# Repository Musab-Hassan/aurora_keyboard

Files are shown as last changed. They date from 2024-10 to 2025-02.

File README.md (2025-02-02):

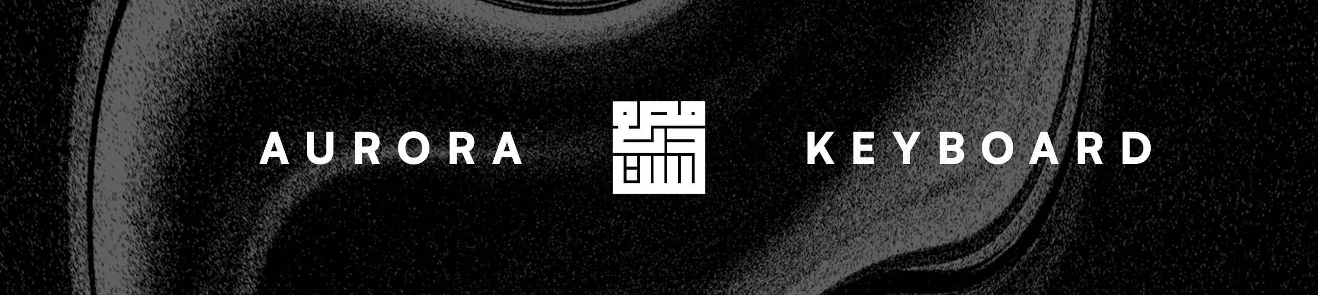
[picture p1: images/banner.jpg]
Aurora Keyboard ⌨️
# 

The Aurora keyboard is a beautifully designed fully split, wireless, ergonomic keyboard that you can build yourself.

**The full build guide can be found in `build_guide/`.**

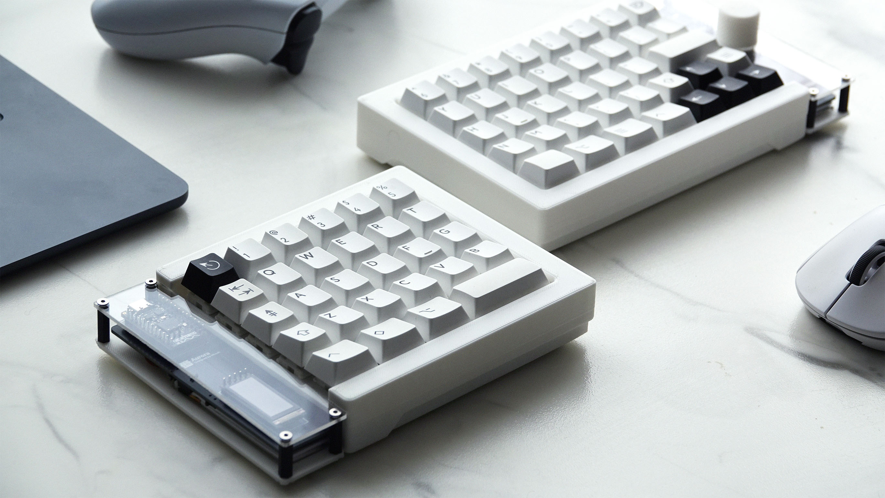
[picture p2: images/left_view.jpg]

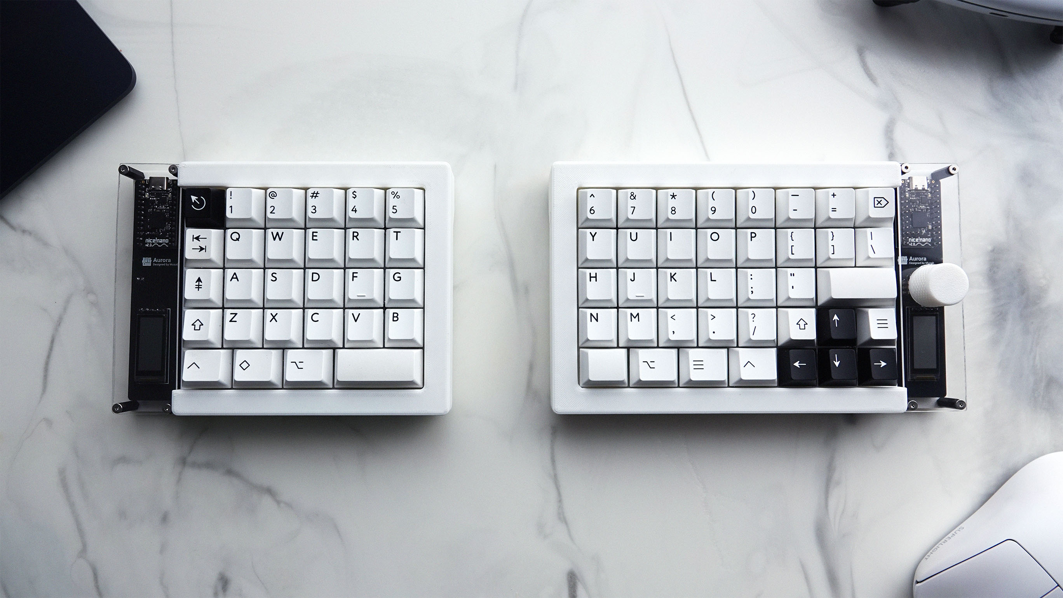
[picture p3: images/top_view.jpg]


**Key Features:**

- Bluetooth and dongle switching
- Ortholinear layout
- 65% layout (full layout with no compromises)
- Per-key RGB (if you can solder them)
- Support for any MX switches and keycaps
- OLED Screen (nice!view)
- Volume knob
- Hotswappable
- ZMK Firmware

## Repo Contents

- **STL Case Files:** 3D-printing-ready case files. You can print these without any CAD skills.
- **SLDPART Case Files:** SolidWorks case files. Modify these to create a custom layout. (Sorry, SolidWorks is the only CAD software I'm proficient in.)
- **Completed PCB Files:** Fabrication-ready routed PCB files, modifiable in KiCAD or Altium. Export them to `.gerber` files for fabrication.
- **Ergogen Files:** Ergogen configuration files used to generate the unrouted PCB. There are two separate folders since the keyboard is asymmetrical. Modify only if fundamental PCB changes are needed.

### Not Included in This Repo

- **ZMK Config:** The ZMK Firmware configuration is stored in [a separate repository](https://github.com/Musab-Hassan/zmk-config-aurora) and is not included here.

## Case Design

The Aurora keyboard uses a [plate-mounted style](https://www.keyboard.university/200-courses/keyboard-mounting-styles-4lpp7) with a top plate and a flat bottom base for each half. The PCB, microcontroller, and nice!view screens are exposed at the open ends and are covered by an acrylic piece.

Due to its ergonomic design and full 65% layout, the cases are asymmetrical, with the right side being larger than the left.

All files were designed in SolidWorks, but they can be opened and modified in other CAD/CAM software.

### Dongle and Bluetooth Switching

The case files also include a dongle case. This dongle is a third nice!nano that functions as a keyboard dongle when connected to a computer via a USB cable or USB-C male-to-male adapter. The dongle case also includes a dongle cover, which, when glued together, allows the dongle to slot into the left side of the keyboard.

The left side features a slot for the dongle. If 3-pin magnetic pogo connector is added to the pogo connector holes within both the dongle case and the left side keyboard slot, the dongle can then magnetically attach and automatically switch to Bluetooth by using the left-side battery when it slots in.

Refer to the build guide for more details.

## PCB Design

The PCB layout and unrouted PCB were generated using Ergogen. Since the two halves have different layouts, separate folders exist for each. My Ergogen skills were not sufficient to configure both in one file.

After Ergogen, the PCB was routed in KiCAD. Routed PCB files are in the `pcb` directory and are fabrication-ready. Download the zip files from the `pcb/gerber` directory and then order them for fabrication.

You can order the PCBs from manufacturers such as PCBWay or JLCPCB.

## Parts List

This list includes all external parts required, excluding the PCB and 3D-printed case files. I’ve also provided the sources where I purchased these parts. However, they may not be the cheapest or best sources. Switches and keycaps are personal preference and should be a significant part of your budget.

### Required Parts

| Part | Quantity | Where I got them from |
| --- | --- | --- |
| nice!nano | 3 (2 if no dongle) | [Typeractive](https://typeractive.xyz/products/nice-nano) |
| nice!view | 2 | [Typeractive](https://typeractive.xyz/products/nice-view) |
| 1N4148W SMD diodes | 70 | [Typeractive](https://typeractive.xyz/products/smd-diodes) |
| MX Hotswap sockets | 70 | [Amazon](https://www.amazon.ca/dp/B0972HB9GY) |
| 750 mAh Thin LiPo Battery | 2 | [Typeractive](https://typeractive.xyz/products/lithium-battery-750mah) |
| JST PH 2.0mm Battery Jack | 2 | [Typeractive](https://typeractive.xyz/products/battery-jack) |
| EC11 Encoder | 1 | [Digikey](https://www.digikey.ca/en/products/detail/alps-alpine/EC11E15244B2/19529170) |
| 0.08" Acrylic Sheet (8" x 12") | 1 | [Amazon](https://www.amazon.ca/dp/B0BK3DN8JR) |
| Alps Micro Switch | 2 | [TyperActive](https://typeractive.xyz/products/power-switch) |
| Panasonic EVQPU Reset Button | 2 | [Typeractive](https://typeractive.xyz/products/reset-button) |
| PCB Mount Stabilizers | 4 | [KBDFans](https://kbdfans.com/collections/keyboard-stabilizer/products/cherry-clip-in-stabilizer-pcb-mount) |
| MX Switches (Preference: I chose Gateron Smoothies) | 70 | [KBDFans](https://kbdfans.com/products/gateron-smoothie-linear-switch) |
| MX Keycaps (Preference: I chose PBTFans BOW) | 70 | [KBDFans](https://kbdfans.com/products/pbtfans-doubleshot-bow) |
| M2.5 6mm Countersunk Screw | 12+ | [Amazon](https://www.amazon.ca/dp/B075RCP71G) or [McMaster Carr](https://www.mcmaster.com/92010A016) |
| M2.5 8mm Hex Standoff | 8+ | [Amazon](https://www.amazon.ca/dp/B0788FR59P) or [McMaster Carr](https://www.mcmaster.com/95947A003) |
| M2.5 14mm Hex Standoff | 8+ | [Amazon](https://www.amazon.ca/dp/B0788FR59P) or [McMaster Carr](https://www.mcmaster.com/95947A009) |

### Optional But Recommended Parts

| Part | Quantity | Why | Where I got them from |
| --- | --- | --- | --- |
| 3 Pin Magnetic Pogo Connector  | 2 | Allows dongle to magnetically snap in and switch to bluetooth | [Amazon](https://www.amazon.ca/dp/B0CPJHQK2F) |
| Rubber Feet  | 8 | Prevents keyboard from slipping | [Amazon](https://www.amazon.ca/dp/B07CNQC695) |
| Neodymium Bar Magnets (60mm x 10mm x 3mm) | 2 | Allows the keyboard to magnetically snap when connected together (case plate has a slot for magnets) | [Amazon](https://www.amazon.ca/dp/B09TKMRRRC) |
| Keyboard Lube or Di-electric grease | 1 | If you want your keyboard to sound good you can lube the switches for it to sound even better (not recommended unless you are very ambitious about keyboards) | [Amazon](https://www.amazon.ca/dp/B09B9RL1QQ) |
| Neoprene Foam Sheet | 1 | Allows you to dampen keyboard sound so it sounds better. Again not recommended unless you really like dampened keyboard sounds. | [Amazon](https://www.amazon.ca/dp/B0B88BLNGQ) |
| SK6812Mini RGB LED | 70 | RGB per key backlight. Only get these if you are very experienced with SMD soldering. They are very difficult to solder by hand. There is also no support in the Aurora ZMK configuration for RGB yet as I am unable to solder them. If you do solder them you will need to add the backlight option in the ZMK config yourself for them to work. | [ClicketySplit](https://clicketysplit.ca/products/sk6812mini-programmable-rgb-led) |

### Required Tools

- Soldering iron (preferably with temperature control)
- Solder (preferably nothing larger than 0.8mm)
- Flux (optional but recommended)
- Tweezers
- FDM or Resin 3D Printer or at least access to one
- Screw driver with the appropriate bit depending on your screws

## License

GPL V3 License

Have fun with your build!

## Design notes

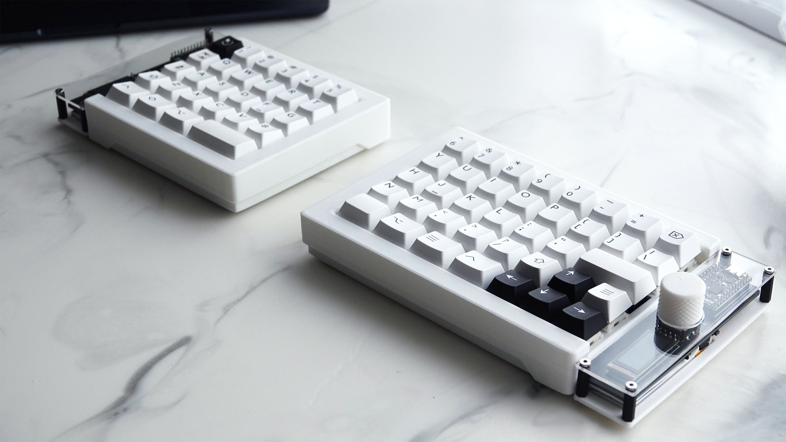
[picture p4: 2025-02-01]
images/right_view.jpg

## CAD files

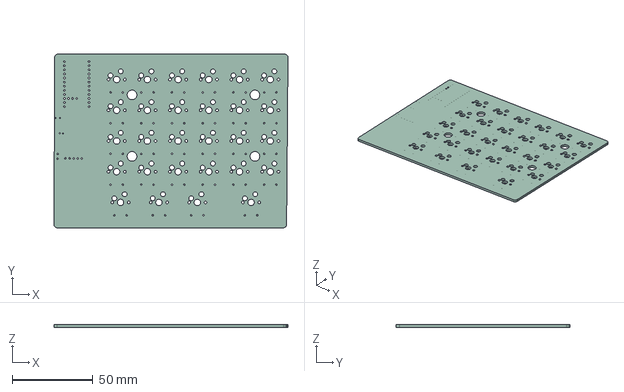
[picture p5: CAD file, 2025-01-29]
case/CAD/pcb/left-pcb.step
145.1 x 107.7 x 1.60 mm

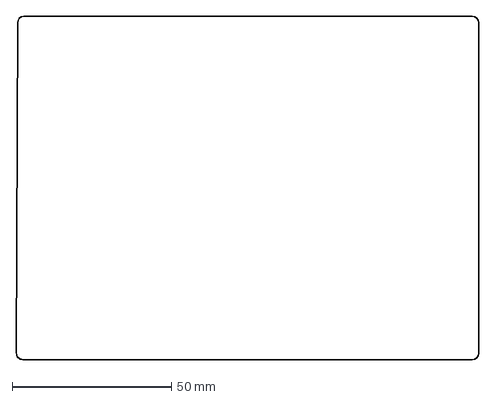
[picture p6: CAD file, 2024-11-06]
left_ergogen/output/outlines/board.dxf
145.1 x 107.7 mm

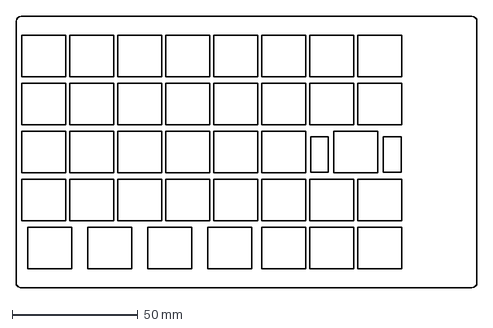
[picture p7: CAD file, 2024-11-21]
right_ergogen/output/outlines/combo.dxf
182.9 x 107.7 mm

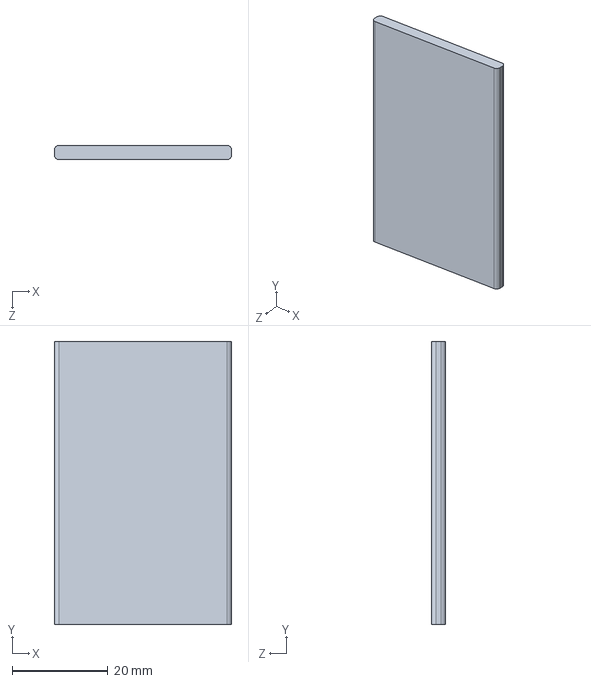
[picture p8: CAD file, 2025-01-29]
case/CAD/battery_placeholder.SLDPRT
37.0 x 59.0 x 3.00 mm

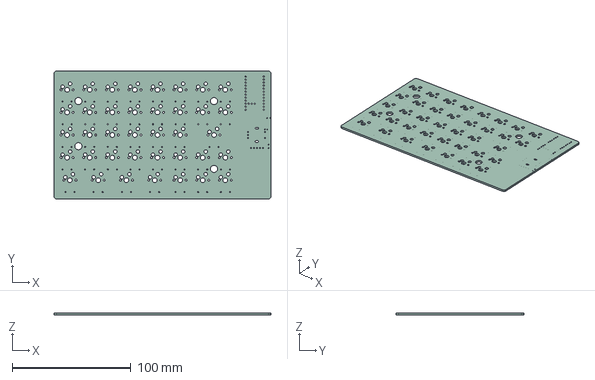
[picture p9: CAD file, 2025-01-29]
case/CAD/pcb/right-pcb.step
182.9 x 107.7 x 1.60 mm

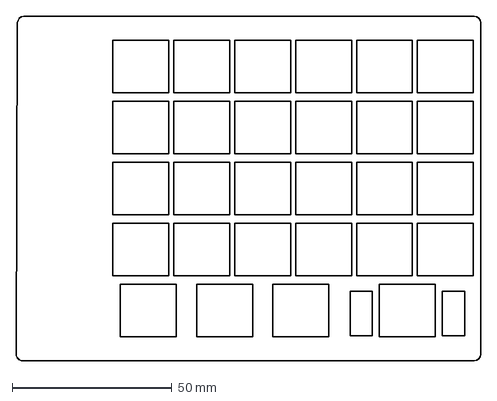
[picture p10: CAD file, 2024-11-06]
left_ergogen/output/outlines/combo.dxf
145.1 x 107.7 mm

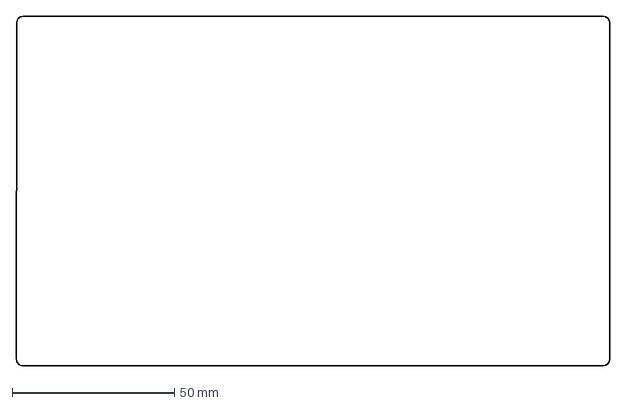
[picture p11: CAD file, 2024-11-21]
right_ergogen/output/outlines/board.dxf
182.9 x 107.7 mm

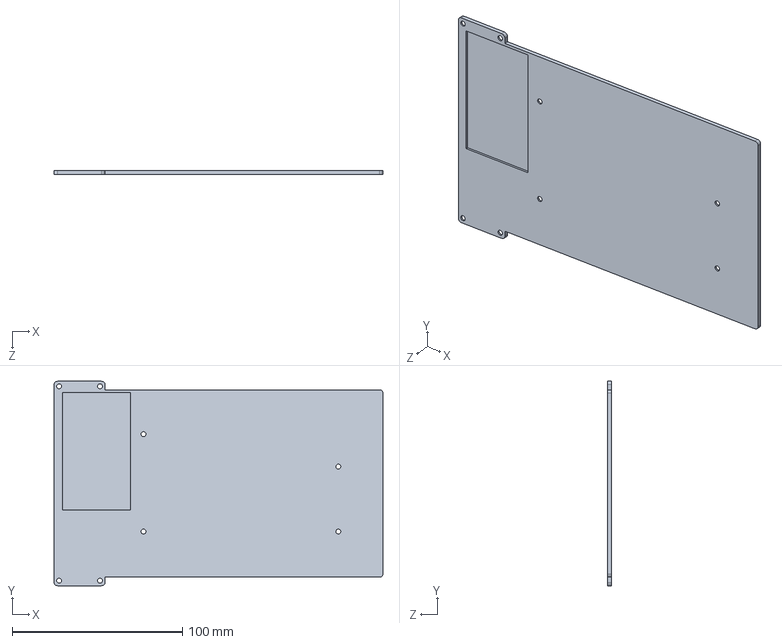
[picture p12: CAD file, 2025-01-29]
case/CAD/right_base.SLDPRT
193.0 x 120.0 x 2.20 mm

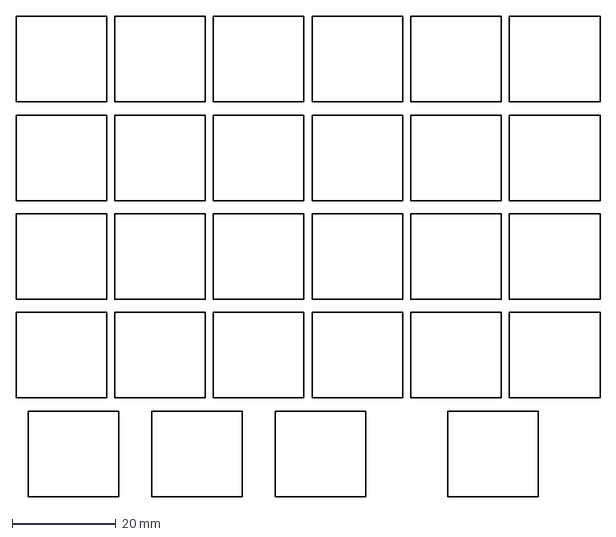
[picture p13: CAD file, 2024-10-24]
left_ergogen/output/outlines/keys.dxf
112.8 x 92.7 mm

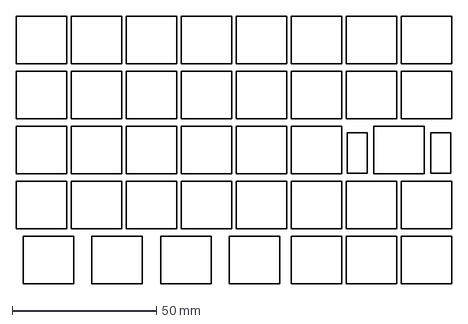
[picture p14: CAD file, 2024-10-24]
right_ergogen/output/outlines/keys_w_stabs.dxf
150.8 x 92.7 mm

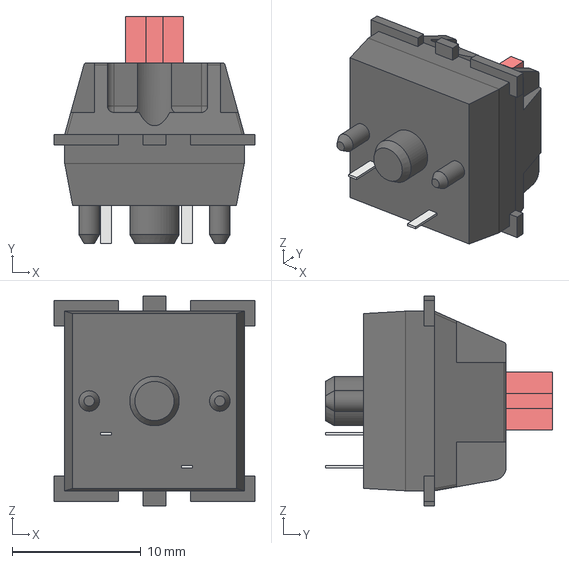
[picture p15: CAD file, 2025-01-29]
case/CAD/switch.step
15.6 x 17.7 x 16.3 mm

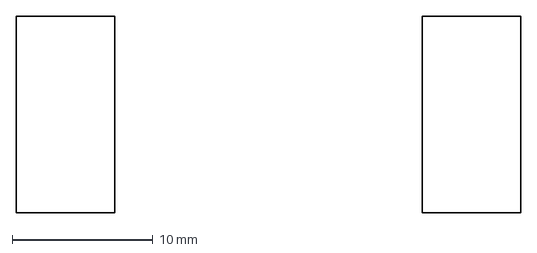
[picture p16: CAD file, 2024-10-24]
left_ergogen/output/outlines/2u_stabilizer.dxf
35.8 x 14.0 mm

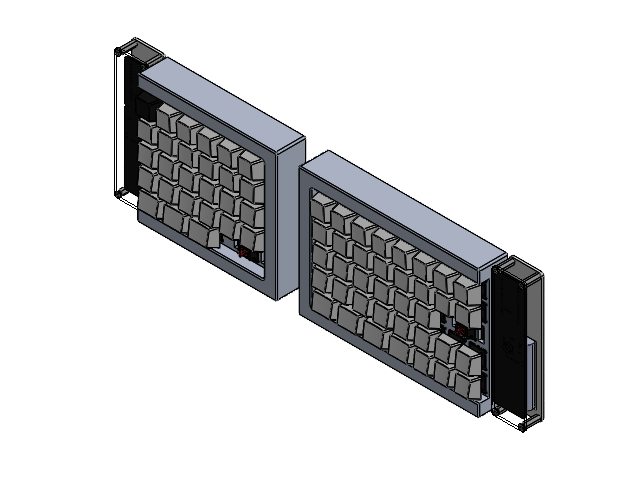
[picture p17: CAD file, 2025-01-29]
case/CAD/combined_assembly.SLDASM
right_plate
right-pcb
switch x 38
1x1 R1 v23 x 17
1x1 R2 v8 x 12
1x1 R3 v8 x 14
1x1 R4 v6 x 14
1x1.25 R1 v7 x 7
92010A018_Passivated 18-8 Stainless Steel Phillips Flat Head Screw x 32
95947A007_Aluminum Female Threaded Hex Standoff x 8
95947A009_Aluminum Female Threaded Hex Standoff x 8
battery_placeholder x 2
right_base
acrylic_holed_shield
left_plate
left_base
Component1.step x 28
Component2.step x 28
acrylic_shield
left-pcb

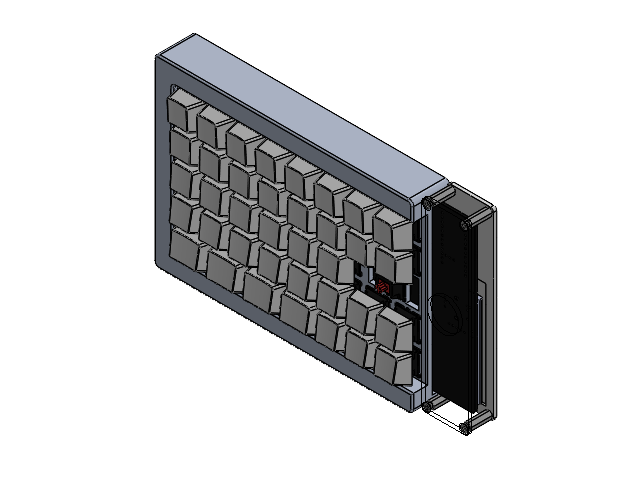
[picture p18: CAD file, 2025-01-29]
case/CAD/right_assembly.SLDASM
right_plate
right-pcb
switch x 38
1x1 R1 v23 x 11
1x1 R2 v8 x 6
1x1 R3 v8 x 8
1x1 R4 v6 x 8
1x1.25 R1 v7 x 4
92010A018_Passivated 18-8 Stainless Steel Phillips Flat Head Screw x 16
95947A003_Aluminum Female Threaded Hex Standoff x 4
95947A009_Aluminum Female Threaded Hex Standoff x 4
battery_placeholder
right_base
acrylic_holed_shield

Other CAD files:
case/CAD/keycaps/1x1 R2 v8.SLDPRT
case/CAD/keycaps/1x1 R3 v8.SLDPRT
case/CAD/keycaps/1x1.25 R1 v7.SLDPRT
case/CAD/keycaps/1x1.25 R4 v6.SLDPRT
case/CAD/acrylic_holed_shield.SLDPRT
case/CAD/acrylic_shield.SLDPRT
case/CAD/dongle.SLDPRT
case/CAD/dongle_cover.SLDPRT
case/CAD/keycaps/1x1 R1 v23.SLDPRT
case/CAD/keycaps/1x1 R4 v6.SLDPRT
case/CAD/keycaps/1x1.25 R2 v4.SLDPRT
case/CAD/keycaps/1x1.25 R3 v5.SLDPRT
case/CAD/left_base.SLDPRT
case/CAD/left_plate.SLDPRT
case/CAD/pcb/left-pcb.SLDPRT
case/CAD/pcb/right-pcb.SLDPRT
case/CAD/right_plate.SLDPRT
case/CAD/standoff_hardware/92010A018_Passivated 18-8 Stainless Steel Phillips Flat Head Screw.SLDPRT
case/CAD/standoff_hardware/95947A003_Aluminum Female Threaded Hex Standoff.SLDPRT
case/CAD/standoff_hardware/95947A009_Aluminum Female Threaded Hex Standoff.SLDPRT
case/CAD/switch.SLDPRT
case/STL/acrylic_holed_shield.STL
case/STL/acrylic_shield.STL
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

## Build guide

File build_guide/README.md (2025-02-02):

# Aurora Keyboard Build Guide

Before getting started, ensure you have fully read through the README.md file in the project root. Make sure you have all the required parts and tools before getting started.

This guide will cover how I built the keyboard and will provide the main steps however it expects you to already understand how mechanical keyboard work and have experience with soldering small components. Having some experience with a soldering iron is sufficient if you decide to just go with the required soldering. The only part that requires exceptional hand soldering skills or a reflow station is if you choose to solder the SMD LEDs. They are exceptionally difficult to solder by hand however they are neither required nor recommended and are entirely optional.

This guide also expects that you made no changes to the pin layout on the nice!nano on each side and are going to use a 3rd nice!nano as a dongle. If you chose to not do these, you can still follow the guide but must [modify the ZMK config](https://github.com/Musab-Hassan/zmk-config-aurora/tree/main/config/boards/shields/aurora) for your keyboard to function properly.

## PCB Ordering

Before starting the build also ensure you have both PCBs and there are no major defects on them. You can order both PCBs from JLCPCB or PCBWay (I chose JLC).

1. Go to the [JLCPcb website](https://jlcpcb.com/)
2. Drag and drop one of the gerber zip files from `pcb/gerber`
3. You only have to change the color (I chose black) and just leave everything else at default
4. Add it to cart and repeat the same steps for the other zip file
5. Place your order

Once you have your PCB we are ready to build!

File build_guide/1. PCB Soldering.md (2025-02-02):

# Soldering the PCB

This part of the guide will walk you through the process of soldering all the necessary components onto the PCB. Follow each step carefully to ensure the keyboard functions properly. If you have a voltmeter, you can perform continuity checks to ensure that all your joints are solid.

## Required Tools and Materials

For this part, you will require the following tools from the README. Ensure you use the correct soldering temperature for your solder (usually higher than 400°C is good). Cold joints will cause problems.

- Soldering iron (preferably with temperature control)
- Solder (preferably nothing larger than 0.8mm)
- Flux (optional but recommended)
- Tweezers

## Board Orientation

Throughout this soldering guide, there will be references to the board back, front, left, and right. It's important to understand what these mean.

The shorter PCB is the "left PCB," while the longer PCB is the "right PCB." Both of these PCBs have solder points on the front and the back. The front of both PCBs is where the logo and the screen are located (see picture below).

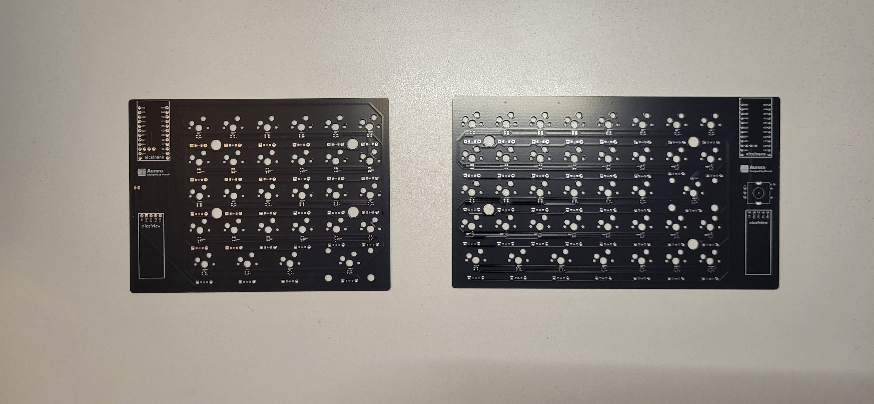
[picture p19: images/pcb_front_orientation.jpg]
Front Orientation


The bottom side is where the diodes and other hidden components go (see picture below).

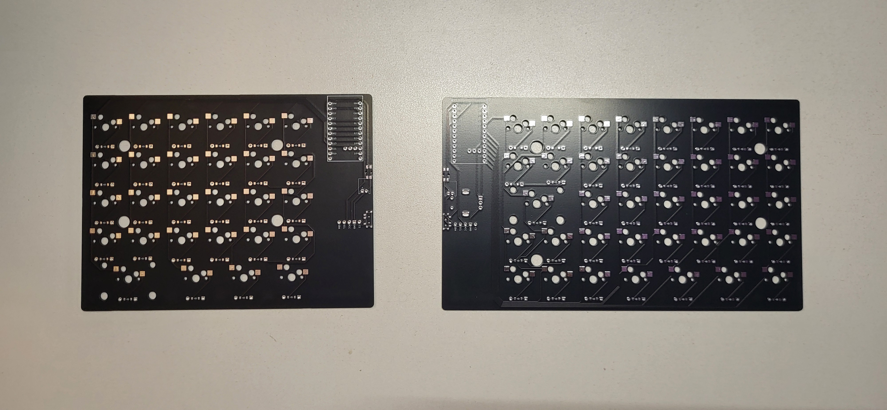
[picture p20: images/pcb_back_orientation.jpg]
Back Orientation


## Step-by-Step Soldering Guide

### Before Starting

If you plan to have per-key RGB backlighting, start by soldering the LEDs. These are surface-mount components and require precision, so doing them first ensures nothing gets messed up once everything else is soldered on. The pads are labeled in the PCB schematic, and you must align them appropriately. For this step, you are on your own as this is the only component I have not added to my build. The ZMK configuration will also need to be modified when you get to Firmware Flashing.

If you do not want to modify the firmware configuration or don't care about RGB, you can skip this step.

### 1. Solder Diodes

Start by soldering the diodes. Each key needs a diode. You can find the diode pads on the back side of the PCB.

Ensure the diode line aligns with the cathode on the solder mask image (see image below).

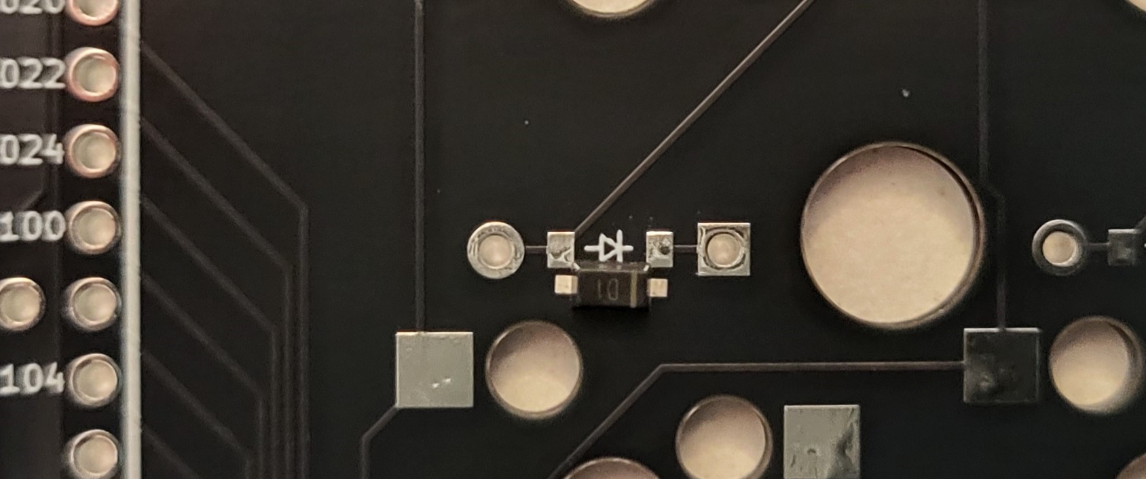
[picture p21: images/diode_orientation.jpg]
Diode Orientation


Make sure you solder them on both PCBs.

> #### Why do we need diodes?
>
> Each key is connected to a column and a row, which identifies it to the microcontroller. This "matrix" allows a lot of keys to exist without using many pins on a microcontroller. Diodes ensure that when a key is pressed, it is always detected even when multiple keys are pressed.

### 2. Solder Hotswap Sockets

The next step is to solder the hotswap sockets to their pads. The hotswap socket pads are located on the same side of the PCB as the diodes. Just like diodes, each key needs a hotswap socket.

Hotswap sockets allow you to easily click in switches and replace them in the future without having to desolder them each time.

The sockets will fit in both orientations, so ensure you orient them in a way that does not block the stem hole for your switches. See the image below for the correct orientation.

|❌ Wrong Orientation|✔️ Correct Orientation|
|--|--|
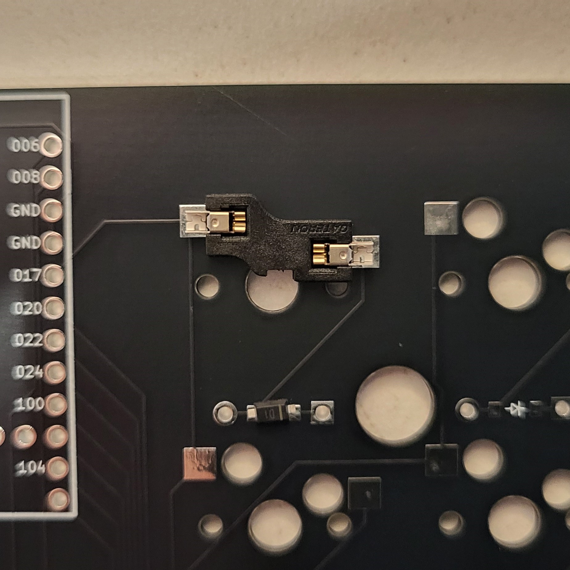
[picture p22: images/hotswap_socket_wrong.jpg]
Incorrect Orientation
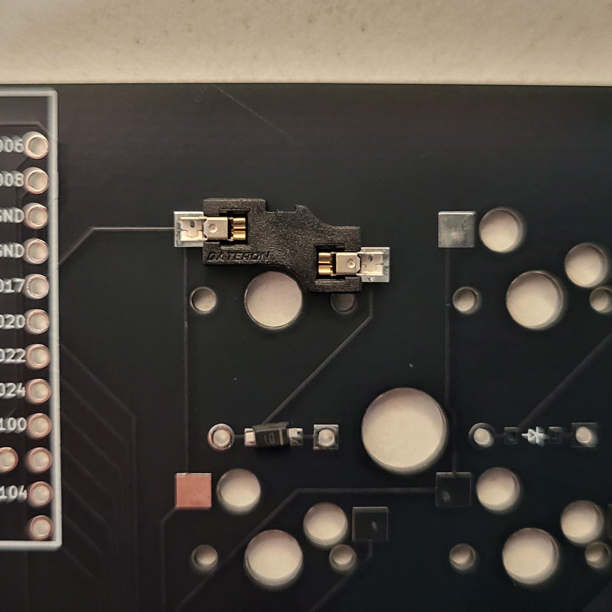
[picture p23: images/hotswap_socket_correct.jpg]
Correct Orientation
|||

Make sure you solder them on both PCBs.

### 3. Solder Power and Reset Switches

Similar to the diodes, continue by soldering the legs on both the power and reset switches. There is only one correct orientation for them, so this step should be easier compared to soldering diodes.

Your final soldered joints should look something like this:

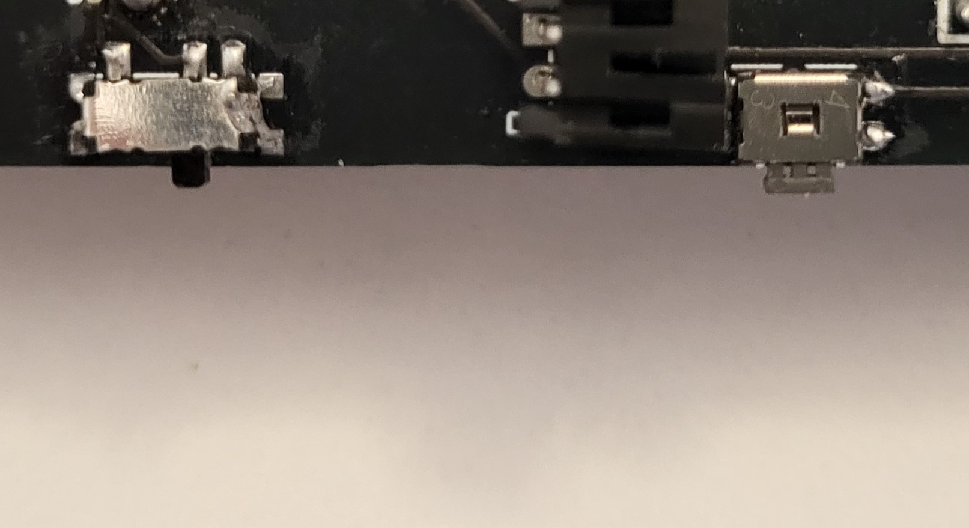
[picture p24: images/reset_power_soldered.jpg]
Soldered joints for power and reset switches


Make sure you solder them on both PCBs.

### 4. Solder Both nice!nanos

The next step is to solder the nice!nano microcontroller onto both boards. The microcontroller should come with three pin headers. Slot them into their respective holes on the front of the PCB and solder the legs sticking out on the back side of the PCB. Ensure the other end of the pins sticks out on the top and not the bottom, as the microcontroller will be soldered onto them.

After soldering the headers, slide the microcontroller onto the pins exposed on the top and solder each pin on the microcontroller. Ensure you make proper joints with a reasonable amount of solder, as cold joints here can cause problems.

Your final solder points should look like this (the mess is because of flux and definitely not because of my soldering skills):

|Front|Back|
|--|--|
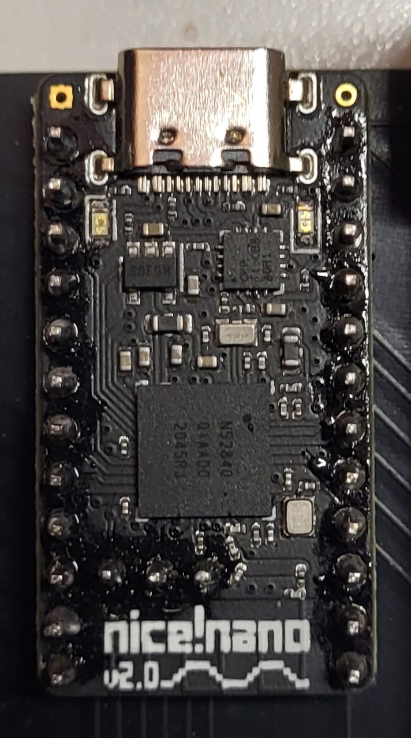
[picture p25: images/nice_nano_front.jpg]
Front
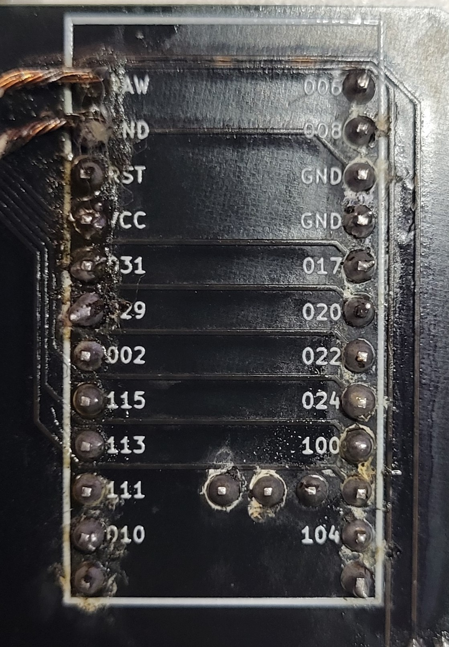
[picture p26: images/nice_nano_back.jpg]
Back
|||

Make sure you solder a nice!nano on both the right and left PCBs.

### 5. Solder Screens

Just like the microcontroller, the nice!view screens should also come with one pin header each. Slot this pin header into its hole and solder the exposed pins on the back of the board.

After soldering the headers, slide the nice!view screens onto the pins exposed on the top and solder each pin. Ensure you make proper joints with a reasonable amount of solder, as cold joints here can cause problems.

Your final solder points should look like this (the mess is because of flux and definitely not because of my soldering skills):

|Front|Back|
|--|--|
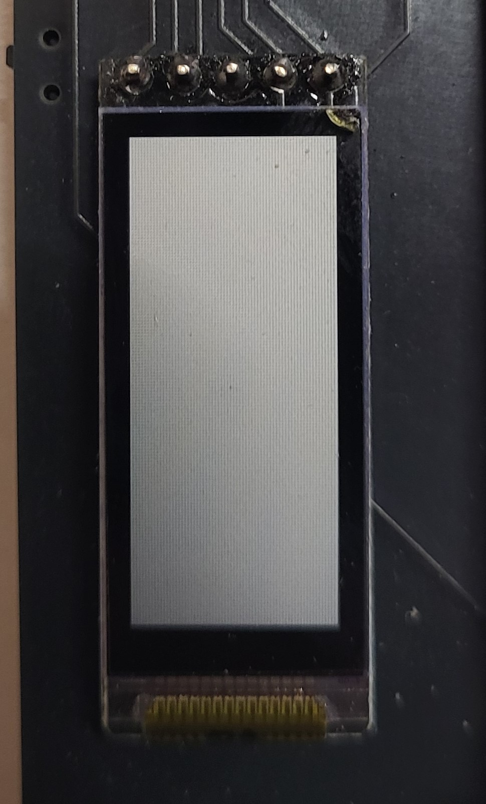
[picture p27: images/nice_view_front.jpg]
Front
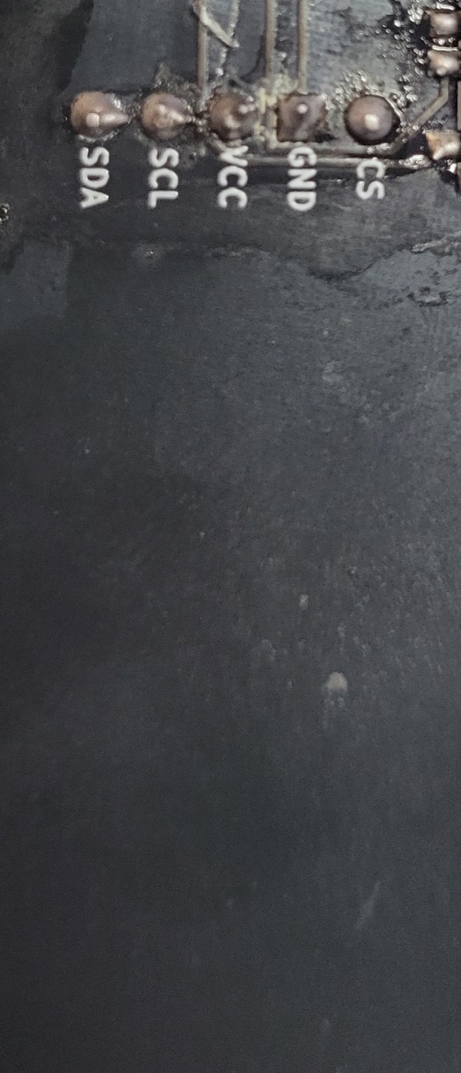
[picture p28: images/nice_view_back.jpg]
Back
|||

### 6. Solder JST Jack

Before starting this step, ensure your battery has a male jack so it can connect to the JST Jack. If it does not (bare wires), you will need to purchase a battery connector and add it to the battery end so it can be connected to the jack. You can also skip this step by just soldering the battery wires directly to the JST Jack holes, however I would not suggest this as this will make future repairs annoying.

If you do have a connector, you can start soldering the JST battery jack now.

Align the JST battery jack on the back side of the PCB. Ensure it is oriented according to the direction marked on the PCB. The exposed pins should stick out on the front of the PCB, where you will solder them. If you solder the jack in the wrong orientation, the battery will not be able to power the microcontroller.

Do not plug in the battery yet; we will do this later during the case assembly.

The final soldered jack should look like this:

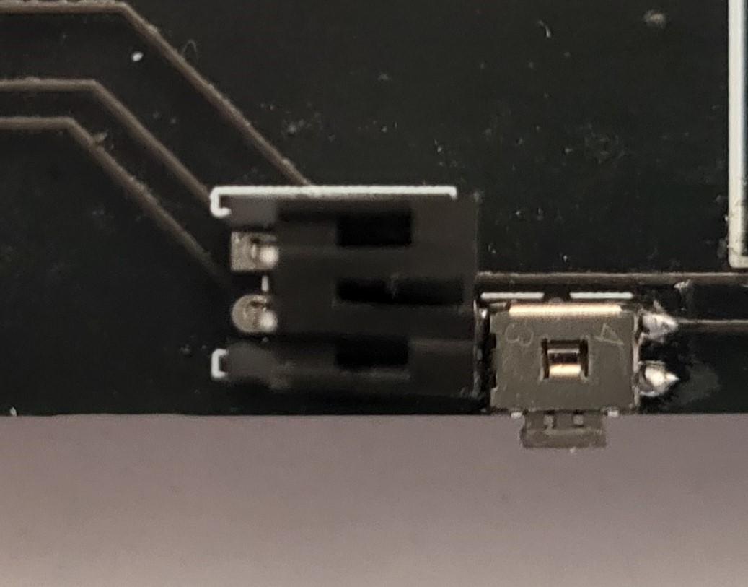
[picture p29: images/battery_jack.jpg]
Battery Jack


Once soldered to both sides, the left PCB is complete. The right PCB just needs one last component to be soldered.

### 7. Solder Right Encoder

Finally, solder the rotary encoder to the right PCB. The encoder should face the front with its legs and pins pushed through their holes.

Once inserted, solder the exposed pins on the back. Leave the legs as they are, as they provide stability but do not have any electrical connections.

### 8. Mount your stabilizers

We are now done with soldering however we do need to add one last component which is mounting our stabilizers to the PCB. The wider keys such as the space bar on the left and the enter on the right side need them to not wobble when they are pressed.

You can find tutorials online on how to mount stabilizers to a PCB (I suggest [this tutorial](https://www.youtube.com/watch?v=kWlRucYPb5g)). I would also highly suggest [lubing and then adding some dampening material](https://www.youtube.com/watch?v=-vhpHjlkRgQ) under your stabilizers to reduce rattling when you press the larger keys.

## Final Checks

As part of the final checks:

- Inspect all solder joints for cold solder or bridges.
- Ensure all components are securely attached.

Congratulations! You’ve successfully soldered the PCB for your Aurora Keyboard.

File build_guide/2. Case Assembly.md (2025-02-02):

# Case Assembly

Assembling the case is the final step in building your keyboard's hardware. This is where you will secure all the components together and have a ready to use keyboard. Follow each step carefully to ensure your build turns out beautiful.

## Required Tools and Materials

For this part, you will only need a screwdriver with a bit appropriate for the screws you purchased.

Also, ensure you have all the printed case STLs with all support material removed.

The printed files required for this part are:

- Left Plate (provided as STL)
- Right Plate (provided as STL)
- Left Base (provided as STL)
- Right Base (provided as STL)
- Right Encoder Knob ([Get from Printables](https://www.printables.com/model/347536-encoder-knob))

> I printed all my parts with a Bambu labs P1P (0.4mm nozzle) printer in white PLA. I would suggest using a slow speed and enabling supports. You can also enable ironing on the top surface for an even better finish.

You can also resin print the "acrylic_cover" files; however, I would advise getting them laser-cut in acrylic or hand-cutting them from an acrylic sheet using a drill and snapping them. See the acrylic piece step below for more details on how to do this.

## Step-by-Step Case Assembly Guide

### 1. Click in Switches

The PCB is a floating PCB, meaning it has no support from underneath or above and is held to the case exclusively by the switches clicked in from the top plate. This simplifies assembly and prevents 3D printing imperfections from interfering with PCB spacing.

To begin assembly, align the PCB with the top plate. Align the hotswap sockets with the cutouts for each key in the plate and start pushing in switches from the top. Do this evenly by starting from each corner and then working toward the middle. Once they are all aligned, give them a firm push to ensure they are properly seated within the hotswap sockets on the PCB. As you insert more switches, the PCB will become more securely attached to the top plate.

Your final PCB and plate assembly should look like the following image.

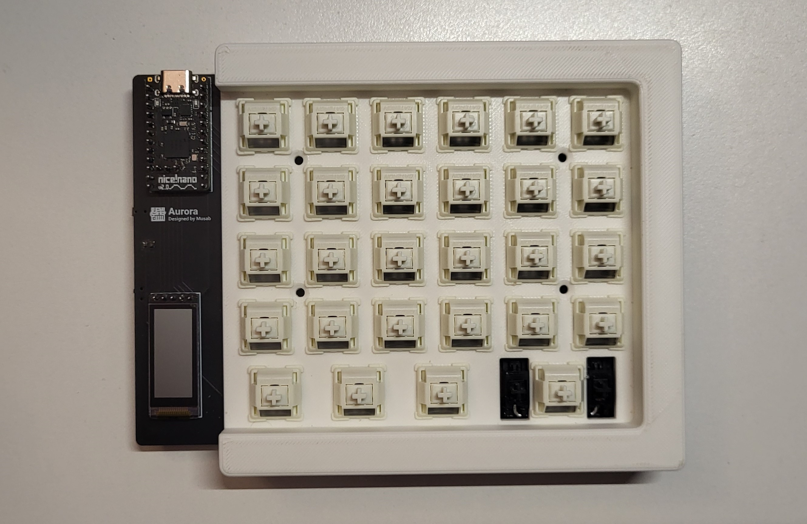
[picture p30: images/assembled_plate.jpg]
Assembled Plate


Ensure this is done for both halves.

**Optional Feature:** There is a slot under the plate to add a neodymium magnet so your keyboard can magnetically attach to the other half when it gets close. You can slot your magnet here (ensure it's in its correct orientation so it attracts) and just hot glue it so it stays secure.

### 2. Prepare Base

Now, prepare the base for mounting with the top plate.

Start by screwing four M2.5 8mm Hex Standoffs with screws from the bottom of the base where the plate holes and base holes align.

Next, screw four M2.5 14mm Hex Standoffs into the end holes where the acrylic piece will be screwed on top.

Lastly, apply [thin double-sided tape](https://www.amazon.ca/dp/B00BXYWXY8) to the cavity in the base where the battery will sit. Align the battery to the bottom and left of the cavity and tape it down with the double-sided tape.

As an additional layer of protection, tape a small piece of thin foam (often included with switches) on top of the battery. This prevents accidental punctures from exposed pins and keeps the battery safe from pressure or sharp contacts.

Ensure you repeat this for both sides and both batteries.

Your prepared base should look like the following image:

**Optional Features:** As an extra noise damper, you can add a layer of Neoprene foam (listed in optional parts) to the base to help with noise reduction and change your keyboard's sound profile. You can also add rubber feet to the bottom to reduce slipping. I have included both in my build, which you can see in the image below.

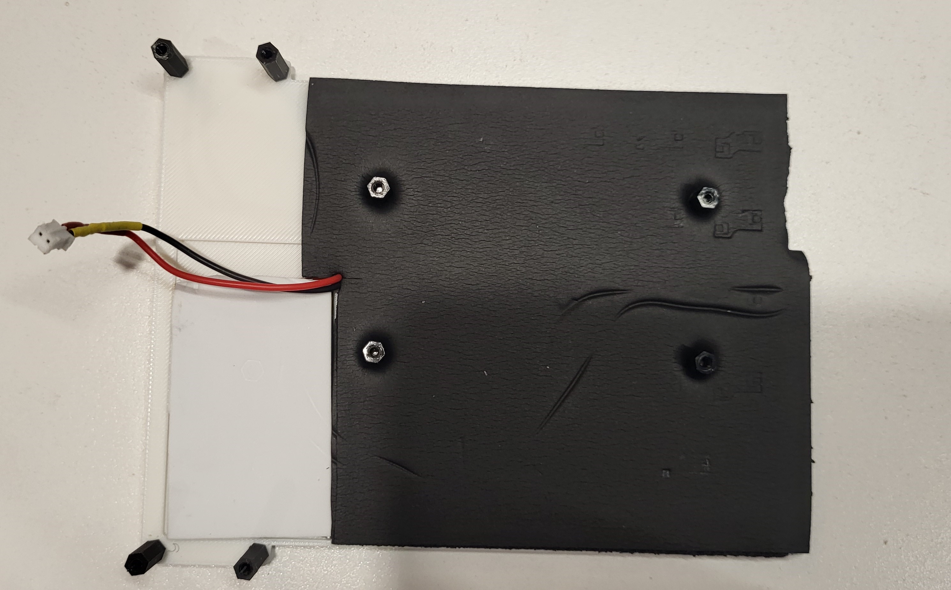
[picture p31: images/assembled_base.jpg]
Assembled Base


### 3. Screw Top Plate to Base and Attach Acrylic Piece

The next step is to screw the top plate to the base. Align the top plate holes with the standoffs on the base and secure them with screws from the top. **Make sure to plug in the battery to the PCB before doing this.**

Once assembled, screw the acrylic pieces onto each side using the exposed standoffs. Ensure the piece with the hole is attached to the right side, as that is where the encoder stem should stick out.

If you are cutting the acrylic piece by hand, use a high-speed drill and the correct-sized bits. Snap your acrylic sheets to the required size (3D print the *acrylic_shield.stl* file to use as a template), then drill the necessary holes. If using a laser cutter, you must **countersink** the holes so the screws fit properly.

### 4. Attach Keycaps and Encoder Knob

The final step is to attach your keycaps and rotary encoder knob. These can simply be pressed in and require no additional assembly.

You can also perform this step **after flashing your firmware**, which I recommend, as it will make disassembly easier if something does not work correctly after flashing.

The build is now complete, and your keyboard is ready to be powered on.

The final assembly should look like the following image:

Final Build

## Final Checks

Before using your keyboard, perform these final checks:

- Ensure all screws are properly tightened but not over-tightened.
- Verify that the battery is securely taped and protected with foam.
- Check that all switches are fully seated in their hotswap sockets.
- Ensure the encoder knob is attached and rotates smoothly.
- Confirm that the acrylic cover is correctly positioned and screwed in.

Once all checks are complete, your Aurora keyboard is fully assembled and ready for firmware flashing!

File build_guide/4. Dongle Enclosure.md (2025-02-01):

# Dongle Enclosure

As a final optional feature, you can add the ability to magnetically snap the dongle within the left keyboard and have it switch over to Bluetooth. This will use more battery but offers a good alternative when you don't want to plug in the dongle.

If you choose to do this, you will need the **3-pin magnetic pogo pins** mentioned in the optional parts, as they will allow your dongle to connect to the left side's battery when snapped in.

## Required Tools and Materials

For this part, you will require the following tools from the README. Ensure you use the correct soldering temperature for your solder (usually higher than 400°C is good). Cold joints will cause problems.

- Soldering iron (preferably with temperature control)
- Solder (preferably nothing larger than 0.8mm)
- Flux (optional but recommended)
- Tweezers
- Hot glue and a hot glue gun

## Assembling the Dongle

Start by assembling the dongle. You will need access to a 3D printer for this part unless you already 3D printed the dongle files during the Case Assembly step.

1. 3D print the **dongle.stl** and **dongle_cover.stl** files.
2. Properly remove all support material from your dongle 3D print.
3. Solder the **RAW** and **GND** pins of your dongle’s nice!nano to two pins on one of the magnetic connectors using wires.
4. Push the nice!nano towards the top of the dongle until it fits snugly.
5. Push the magnetic connector into the bottom hole (you might need to clip the supports on the sides to make it fit).

Your dongle should now function as it did before but will be enclosed in its housing. **Do not add the cover yet**, as it will make diagnosing problems difficult.

## Case Socket Connections

The left plate has an opening on the top right where the dongle is supposed to fit. We now need to add the other magnetic connector to the enclosure so the dongle clicks in and has secure electrical contacts.

1. Remove the keycaps from the left device (do not remove any switches), turn it off, and unscrew the plate from the base.
2. Flip the keyboard around and solder two wires to the **RAW** and **GND** pins on the back of the left keyboard's nice!nano.
3. Orient the other magnetic connector so it attracts the dongle's magnetic connector and does not repel it.
4. Solder the two wires soldered in step 2 to the same pins you soldered to the magnetic connector on the dongle.
5. Clip the supports on the magnetic connector so it fits in its enclosure.
6. Push the connector into its hole within the top plate.
7. Turn your left device on and slot the dongle into the opening.
8. Check that the dongle turns on (blue light flash) and appears as a Bluetooth device on your computer. If it does not, ensure your solder points are properly connected and that there are no broken or cold joints. Also, verify that your orientation matches on both ends and that you soldered the same pins to the corresponding pins.
9. If everything works correctly, remove the dongle from the enclosure and turn the left device off again.
10. Apply hot glue to the pins behind both magnetic connectors to ensure the connections do not move.
11. Glue the dongle cover onto the dongle.
12. Screw the base back onto the left device and reassemble it.

Congratulations! You should now have a dongle housing within your left keyboard that also allows your keyboard to interface via Bluetooth. Enjoy your Aurora build!

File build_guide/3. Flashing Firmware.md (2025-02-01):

# Flashing Firmware

We have reached the last step in getting your keyboard running. The next section will only cover quality-of-life changes. This is the final required section and is also the easiest. This is the moment when your keyboard will finally come to life.

If you are familiar with ZMK and would like to modify the firmware, you can fork the [ZMK Config for this keyboard](https://github.com/Musab-Hassan/zmk-config-aurora/) and build your own firmware to flash. If you added per-key LEDs during the soldering stage, you must create your own configuration to get them working, as I have not added support for them yet.

## Download the Firmware Files

If you would like to use the pre-built firmware, follow these steps to download it:

1. Go to the [Actions tab of the ZMK-config-aurora repo](https://github.com/Musab-Hassan/zmk-config-aurora/actions/workflows/build.yml).
2. Click on the latest run that has a green checkmark.
3. Scroll down to **Artifacts** and download the firmware zip file.
4. Extract the firmware files and store them somewhere you can easily find them.

## Flash Firmware

Once you have the firmware downloaded, you can start flashing the firmware onto each of the three devices (right side, left side, dongle). When flashing the firmware, keep both sides of the keyboard off (battery switch off). They can still receive power from the USB port even when off, as the switch only disconnects the battery.

To flash the firmware:

1. Connect one of the three devices to your computer using a USB-C cable.
2. Press the reset button twice (located above the power switch).
3. The microcontroller should mount as a flash drive on your computer. Drag the correct firmware file for that device onto the microcontroller.
4. The microcontroller should disconnect and reconnect with the "Aurora" keyboard name.
5. Repeat these steps for the other two devices.

Once all three devices are flashed, disconnect them all and connect the dongle to your computer with a USB-C cable. Once the dongle is connected, turn on both keyboard devices, and you should now have a functional keyboard!

## Final Checks

As a final check, ensure all your keys work properly by using a [Key Tester](https://en.key-test.ru/) and pressing every key. Also, turn and press the encoder knob to see if the volume changes properly.

If a key does not register, try pressing the switch in further with some pressure, as it might not be seated properly in the hotswap socket. If it still does not work, the diode for that key might not be connected properly and may need to be resoldered.

If everything else looks good, your Aurora keyboard is now complete.

You can now stop and continue using your keyboard or move on to the optional features, such as a dongle enclosure, magnetic dongle snapping to allow Bluetooth, and other quality-of-life improvements.

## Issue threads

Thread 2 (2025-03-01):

Cost

sa7mon, 2025-03-01:
Thank you for this excellent design! I was wondering if you could provide the ballpark cost for the build excluding switches and keycaps?

Musab-Hassan, 2025-03-01:
I have listed all the parts in the part list on the bottom of the README with the vendors that I purchased them from. These were the ones that I found the most convenient to order from and who ship to Canada however they are by no means the cheapest. You can probably find these parts for cheaper from other US only vendors.

The final cost for all the required parts from the sources I have listed comes down to $280 CAD which is around $195 USD (not including shipping). Another cost not included is both your PCBs which will cost you $40 USD after shipping to order from JLCPCB.
The case should cost you a couple dollars at most if you own a 3D printer. They use around 400g of filament combined.

Your final cost should be around $250-$280 USD depending on shipping. Of course, your keycaps and switches are on top of that.

My build cost me $380 USD since I bought an expensive key cap set.

Closed 2025-03-24.

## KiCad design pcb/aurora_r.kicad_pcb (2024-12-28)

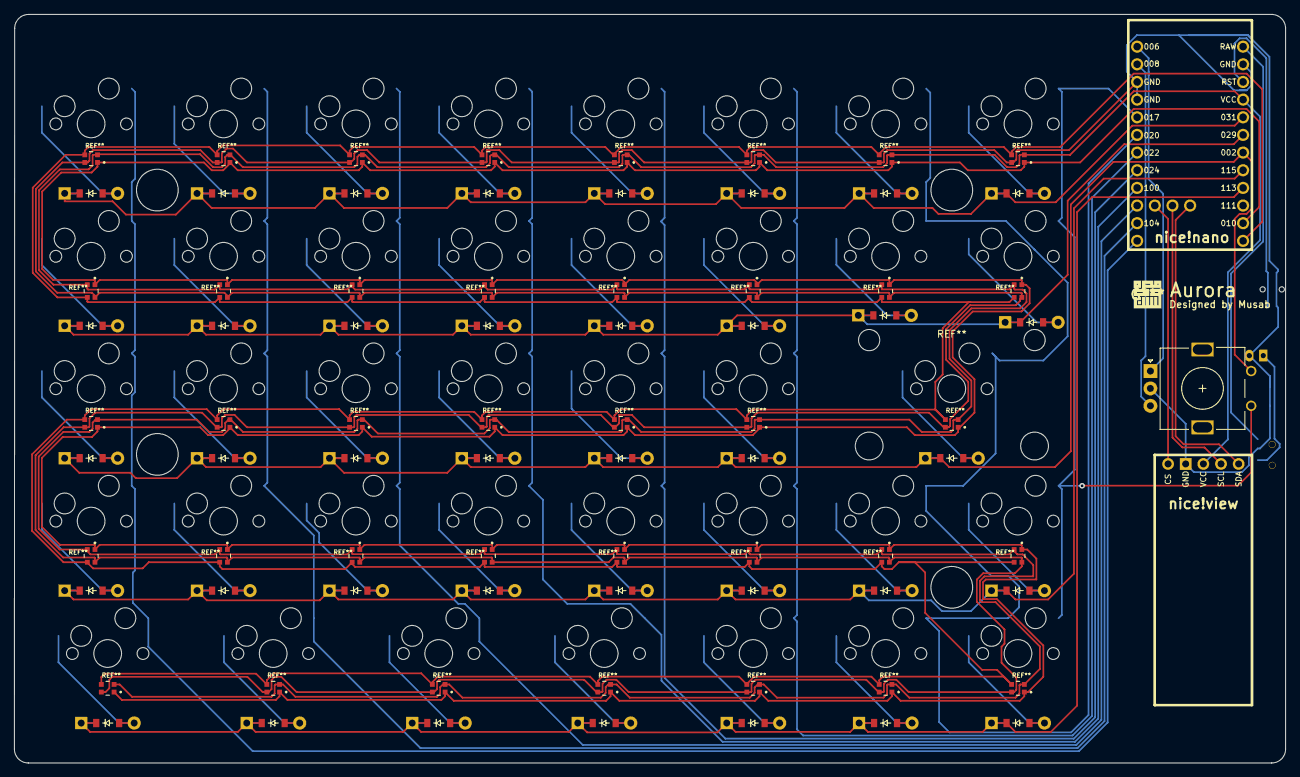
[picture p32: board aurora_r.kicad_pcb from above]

Board: 2 copper layers, 182.9 x 107.7 mm, 82 parts (0 on the bottom side), 61 nets.

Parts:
B1: Panasonic_EVQPUL_EVQPUC
D1, D2, D3, D4, D5, D6, D7, D8, D9, D10, D11, D12, D13, D14, D15, D16, D17, D18, D19, D20, D21, D22, D23, D24, D25, D26, D27, D28, D29, D30, D31, D32, D33, D34, D35, D36, D37, D38: ComboDiode
JST1: JST_PH_S2B-PH-K_02x2.00mm_Angled
MCU1: nice_nano
ROT1: rotary_encoder
S1, S2, S3, S4, S5, S6, S7, S8, S9, S10, S11, S12, S13, S14, S15, S16, S17, S18, S19, S20, S21, S22, S23, S24, S25, S26, S27, S28, S29, S30, S31, S32, S33, S34, S35, S36, S37, S38: MX
T1: SPDT_C128955
niceView1: niceView; niceView_headers

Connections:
BAT: JST1.1, T1.2
GND: B1.1, JST1.2, MCU1.3, MCU1.4, MCU1.23, ROT1.C, niceView1.2
P002: D17.1, D18.1, D19.1, D20.1, D21.1, D22.1, D23.1, MCU1.18, ROT1.1
P006: MCU1.1, ROT1.A
P008: MCU1.2, ROT1.B
P011: MCU1.10, S5.2, S6.2, S19.2, S26.2, S34.2
P017: MCU1.5, ROT1.2, S15.2, S16.2, S31.2, S38.2
P020: MCU1.6, S13.2, S14.2, S23.2, S30.2, S37.2
P022: MCU1.7, S11.2, S12.2, S22.2, S29.2, S36.2
P024: MCU1.8, S9.2, S10.2, S21.2, S28.2
P029: D1.1, D3.1, D5.1, D7.1, D9.1, D11.1, D13.1, D15.1, MCU1.19
P031: D2.1, D4.1, D6.1, D8.1, D10.1, D12.1, D14.1, D16.1, MCU1.20
P100: MCU1.9, S7.2, S8.2, S20.2, S27.2, S35.2
P101: MCU1.31, niceView1.1
P102: MCU1.32, niceView1.4
P104: MCU1.11, S3.2, S4.2, S18.2, S25.2, S33.2
P106: MCU1.12, S1.2, S2.2, S17.2, S24.2, S32.2
P107: MCU1.33, niceView1.5
P113: D32.1, D33.1, D34.1, D35.1, D36.1, D37.1, D38.1, MCU1.16
P115: D24.1, D25.1, D26.1, D27.1, D28.1, D29.1, D30.1, D31.1, MCU1.17
RAW: MCU1.24, T1.1
RST: B1.2, MCU1.22
VCC: MCU1.21, niceView1.3
alt_modrow: D35.2, S35.1
ctrl_modrow: D33.2, S33.1
down_arrow_modrow: D37.2, S37.1
eight_bottom: D31.2, S31.1
eight_num: D16.2, S16.1
eight_top: D15.2, S15.1
enter_home: D23.2, S23.1
five_bottom: D28.2, S28.1
five_home: D21.2, S21.1
five_num: D10.2, S10.1
five_top: D9.2, S9.1
four_bottom: D27.2, S27.1
four_home: D20.2, S20.1
four_num: D8.2, S8.1
four_top: D7.2, S7.1
left_arrow_modrow: D36.2, S36.1
one_bottom: D24.2, S24.1
one_home: D17.2, S17.1
one_num: D2.2, S2.1
one_top: D1.2, S1.1
right_arrow_modrow: D38.2, S38.1
seven_bottom: D30.2, S30.1
seven_num: D14.2, S14.1
seven_top: D13.2, S13.1
six_bottom: D29.2, S29.1
six_home: D22.2, S22.1
six_num: D12.2, S12.1
six_top: D11.2, S11.1
space_modrow: D32.2, S32.1
super_modrow: D34.2, S34.1
three_bottom: D26.2, S26.1
three_home: D19.2, S19.1
three_num: D6.2, S6.1
three_top: D5.2, S5.1
two_bottom: D25.2, S25.1
two_home: D18.2, S18.1
two_num: D4.2, S4.1
two_top: D3.2, S3.1

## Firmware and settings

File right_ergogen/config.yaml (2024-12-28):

units:
  visual_x: 17.5
  visual_y: 16.5
  mod_x_width: 1.25u-1.05
  px: cx + 4
  py: cy + 4
  

  # Stabalizer cutout
  u: U # Ensure we are using 19.05!
  stabilizer_width: 7
  stabilizer_height: 14
  stabilizer_offset: -1 # This means south stabs, use `orient` to rotate them for north facing scenarios
  stabilizer_spacing_2u: u / 2 + stabilizer_width / 2 + ((23.8 / 2) - (14 / 2) - (stabilizer_width / 2)) # The complex formula has two magic numbers. 14 is the size of a switch cutout for a plate. 23.8 is the distance between each stabilizer on a 2-2.75u stabilizer, as specified by Cherry

points:
  zones:
    matrix:
      anchor:
        shift: [100, -100]
      columns:
        one:
          key:
            column_mark: 1
            column_net: P106
        two:
          key:
            column_mark: 2
            column_net: P104
        three:
          key:
            column_mark: 3
            column_net: P011
        four:
          key:
            column_mark: 4
            column_net: P100
        five:
          key:
            column_mark: 5
            column_net: P024
        six:
          key:
            column_mark: 6
            column_net: P022
        seven:
          key:
            column_mark: 7
            column_net: P020
        eight:
          key:
            column_mark: 8
            column_net: P017
      rows:
        top:
          row_net: P029
        num:
          row_net: P031

    enterrow:
      anchor:
        shift: [100, -100-u]
      columns:
        one:
          key:
            column_mark: 1
            column_net: P106
        two:
          key:
            column_mark: 2
            column_net: P104
        three:
          key:
            column_mark: 3
            column_net: P011
        four:
          key:
            column_mark: 4
            column_net: P100
        five:
          key:
            column_mark: 5
            column_net: P024
        six:
          key:
            column_mark: 6
            column_net: P022
        enter:
          key:
            shift: [0.5u, 0]
            width: 2u-1
            column_mark: 7
            column_net: P020
      rows:
        home:
          row_net: P002

    bottomrow:
      anchor:
        shift: [100, -100-2u]
      columns:
        one:
          key:
            column_mark: 1
            column_net: P106
        two:
          key:
            column_mark: 2
            column_net: P104
        three:
          key:
            column_mark: 3
            column_net: P011
        four:
          key:
            column_mark: 4
            column_net: P100
        five:
          key:
            column_mark: 5
            column_net: P024
        six:
          key:
            column_mark: 6
            column_net: P022
        seven:
          key:
            column_mark: 7
            column_net: P020
        eight:
          key:
            column_mark: 8
            column_net: P017
      rows:
        bottom:
          row_net: P115
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

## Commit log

2024-10-16 Aurora left pcb completion
    [2u_stabilizer.dxf, aurora_l.kicad_pcb, board.dxf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]
2024-10-16 Refine left board further
    [aurora_l.kicad_pcb]
2024-10-16 Complete right PCB
    [2u_stabilizer.dxf, aurora_l.kicad_pcb, aurora_r.kicad_pcb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]
2024-10-18 Add stab holes and extended base to PCB
    [aurora_l.kicad_pcb, aurora_r.kicad_pcb]
2024-10-24 Key clearance fixes and mounting hole placement fixes
    [2u_stabilizer.dxf, aurora_l.kicad_pcb, aurora_r.kicad_pcb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]
2024-10-24 Plate case
2024-10-24 Generate output CAD files
    [aurora_r.kicad_pcb]
2024-10-27 Left PCB dimensioning tweaks
    [aurora_l.kicad_pcb]
2024-10-27 Fixed left PCBs with routing
    [aurora_l.kicad_pcb, aurora_r.kicad_pcb]
2024-10-27 Right PCB dimensioning tweaks
    [aurora_r.kicad_pcb]
2024-11-02 Redesign left PCB board layout
    [aurora_l.kicad_pcb, board.dxf, combo.dxf]
2024-11-06 Left PCB pin layout fixes and full routed pcb
    [aurora_l.kicad_pcb, board.dxf, combo.dxf]
2024-11-21 Full redesign of right side with rotary encoder
    [aurora_r.kicad_pcb, board.dxf, combo.dxf]
2024-11-21 Right full routed PCB
    [aurora_r.kicad_pcb]
2024-11-21 Add stab holes to PCBs
    [aurora_l.kicad_pcb, aurora_r.kicad_pcb]
2024-12-26 Minor adjustment to left pcb
    [aurora_l.kicad_pcb, aurora_r.kicad_pcb]
2024-12-26 Rotary encoder pinout fixes
    [aurora_r.kicad_pcb]
2024-12-28 Pin changes on encoder button
    [aurora_r.kicad_pcb]
2025-01-29 Add STL and CAD case files
    [1x1 R1 v23.SLDPRT, 1x1 R2 v8.SLDPRT, 1x1 R3 v8.SLDPRT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]
2025-02-01 Add Dongle Enclosure
2025-02-02 Add gerber files and clarify pcb ordering
